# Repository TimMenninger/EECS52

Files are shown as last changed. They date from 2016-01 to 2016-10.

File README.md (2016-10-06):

# EECS52
This contains my work for EE/CS 52, in which I created and am currently writing
firmware for an MP3 player running on an Intel 80188 processor. I (TimMenninger)
am the only contributor.  When pushing/pulling from a computer in the EE lab,
I unknowingly pushed using a classmate's Git account.

Assembly (.ASM) source can be found in Software/CPU/src.  Hardware descriptions
in ABEL (.ABL) can be found in Software/ABEL/src.

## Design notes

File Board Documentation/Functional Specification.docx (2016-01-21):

# 80188 MP3 Jukebox

# Functional Specification

Tim Menninger

# Description

This is the MP3 Jukebox running on an 80188 processor. It plays MP3 files that are stored on an SD memory card or IDE hard drive. Its basic functions include:

- Skip to Next Track
- Skip to Previous Track
- Play
- Pause
- Stop
- Repeat Song
- Repeat Playlist
- Fast Forward
- Reverse
- Scan
- Volume

Each of these will be connected to a button except for volume, which will be controlled by a rotary switch. These are described in the user interface section.

Songs stored on this device will be able to range from one second to as long as memory permits. These songs will be played using an onboard MP3 decoder chip. When playing back, the MP3 Jukebox will require speakers or headphones be plugged in for music to be heard. The system will be fully functional otherwise when being used with no audio output connected.

For ease of use, the MP3 Jukebox will include an LCD status display which will display the status of the system. When the user presses a button, the screen will display a summary of what in the system has changed, if anything, and when music is playing, the screen will display the song name, artist, album if applicable and the time in the song that is being played.

# Global Variables

None.

# Inputs

## Buttons

Each function listed in Description and described in User Interface will have a button or rotary encoder. Some functions are overloaded onto the same button.

- Button 1 Play, Pause
- Button 2 Previous Track, Rewind
- Button 3 Next Track, Fast Forward
- Button 4 Stop
- Button 5 Repeat Song, Repeat Playlist, Repeat Segment
- Button 6 Scan
- Rotary Switch 1 Volume
- Rotary Switch 2 Miscellaneous

For debugging purposes, there will be a trap button, which will allow the programmer to trap the system. This button will stop the processor from reading and executing code.

- Button 7 Trap

## Power

There will be a power switch on the machine. When switched on, the machine will draw power and have the capability to play. When switched off, this capability will not exist even if a power supply is provided. There will also be an input for power supply. With no power, the MP3 Jukebox cannot play audio files.

- Switch 1 Power Switch
- Port 1 Power Supply

## Playback

In addition to these switches, there will also be an SD Card input from which songs are read and played and an audio port to plug in speakers, headphones, etc. for playback of said songs.

- SD Card Input Songs read from SD Card
- IDE Hard Drive Songs can also be read from an IDE hard drive
- Port 2 Audio Output

# Outputs

## Display

There will be an LCD display on board that displays the status of the system. This display will be four lines. Exactly what appears on this display is described in detail in User Interface.

## Audio

There will be a port that plays the music that is read from memory. Headphones, speakers, etc. can be plugged in for playback.

# User Interface

## Buttons

There is one button for both playing and pausing the song. If the state of the system is such that a file is being played, then pressing this button will pause the song. In any other state (paused, stopped) such that there is power being supplied, pressing this button will play the current song on the playlist.

There is one button for both skipping to the previous track and rewinding. When pressed, the track is not skipped until release of the button. At the release of the button, the system will skip to the beginning of the current song unless the song is in its first three seconds of playing. In this case, it will skip to the beginning of the previous song on the playlist. If the button is held for more than two seconds, then the system begins to rewind from the current place in memory until the user releases the button. The speed of rewind is 2x for the first 10 seconds of rewind (twelve seconds after initial button press) and then 4x from there after. If the beginning of the current song is reached during rewind, it will begin rewinding from the end of the previous song.

Similar to the previous/rewind button, there is one button for skipping forward and fast forwarding. Without loss of generality, this works exactly the same as rewinding except in the opposite direction. The only exception is the forward skip function always skips to the beginning of the next song on the playlist regardless of location of playback in the current song.

The stop button, when pressed, will stop play and lose the spot of the current playback. To begin playing again, the play button must be pressed and play will begin at the beginning of the playlist.

There will be a toggle option for repeating music. There can be repeat off, repeat song and repeat playlist. On repeat off, the music will stop playing at the end of the playlist. This would be equivalent to pressing stop at the end of the last song. On repeat song, the song currently playing will be repeated. This would be equivalent to pressing the previous skip every time the current song ends. Finally, there will be a repeat playlist which will begin playing from the beginning of the playlist after the end of the last song in the playlist. Finally, there will be repeat segment. When repeat segment is turned on, the location of music is remembered as point A. The user can then use the miscellaneous rotary dial to choose an offset (in time) to point B. Pressing the repeat button again will cause the system to repeat the segment from point A to point B, skipping to point A whenever point B is reached. If the time offset is 0 on the second press of the repeat button (i.e. the rotary switch was not touched), the repeat option will continue to toggle repeat options. Turning off this feature after choosing points A and B can be done by pressing the repeat button again or the scan button. The default value for this is repeat off.

The scan button will be a toggle button. When on, it will play the first [integer] seconds of each song. The integer used here can be altered by the miscellaneous rotary dial and can range from 1 to 15 seconds. At the end of those seconds, it will skip to the next song. To stop scanning, the user presses the scan button again to toggle off. This feature will respect the repeat option—if there is no repeat and scan reaches the end of the playlist, music will stop. If there is repeat song, this will continuously play the first five seconds of the same song. The default value for this is scan off and scan time 5 seconds.

The trap button will allow the user/programmer to trap into the kernel and should be used for debugging purposes only. Pressing the trap button during operation will cause the music player to stop playing.

## Dials

The volume rotary dial will control the volume of the output. This particular dial will be one that can rotate forever without reaching some bound. Rotating it counterclockwise will turn the volume down and rotating it clockwise will turn the volume up.

The miscellaneous rotary dial will be used for certain options. It will allow the user to scroll display options while the song is playing. If the user desires to repeat a segment, this dial will control the length of time that is recorded. Finally, when in scan mode, this dial will control how much time each song plays before scanning to the next song.

## Display

When a song is playing, the display will show the song title on the first line, the artist on the second line, the album on the third line and the time in the song on the fourth line. Additionally, on the fourth line on the left side will be an icon for the state of the music player. This could be the right-facing triangle for play, the double-bar pause button or double-triangles for skipping, fast forwarding and rewinding.

If the user scrolls, the bottom line of the display will change. Other display options include the repeat status (off, song, playlist, segment) of the song and a line that shows the progress into the song. When the music is stopped, nothing will be written on the display.

## Memory

Songs will be read from an IDE hard drive by default. If there is an SD chip in the SD slot, then music will be read from there.

# Error Handling

None.

# Algorithms

None.

# Data Structures

None.

# Limitations

This MP3 player currently does not play music.

# Known Bugs

None.

# Special Notes

None.

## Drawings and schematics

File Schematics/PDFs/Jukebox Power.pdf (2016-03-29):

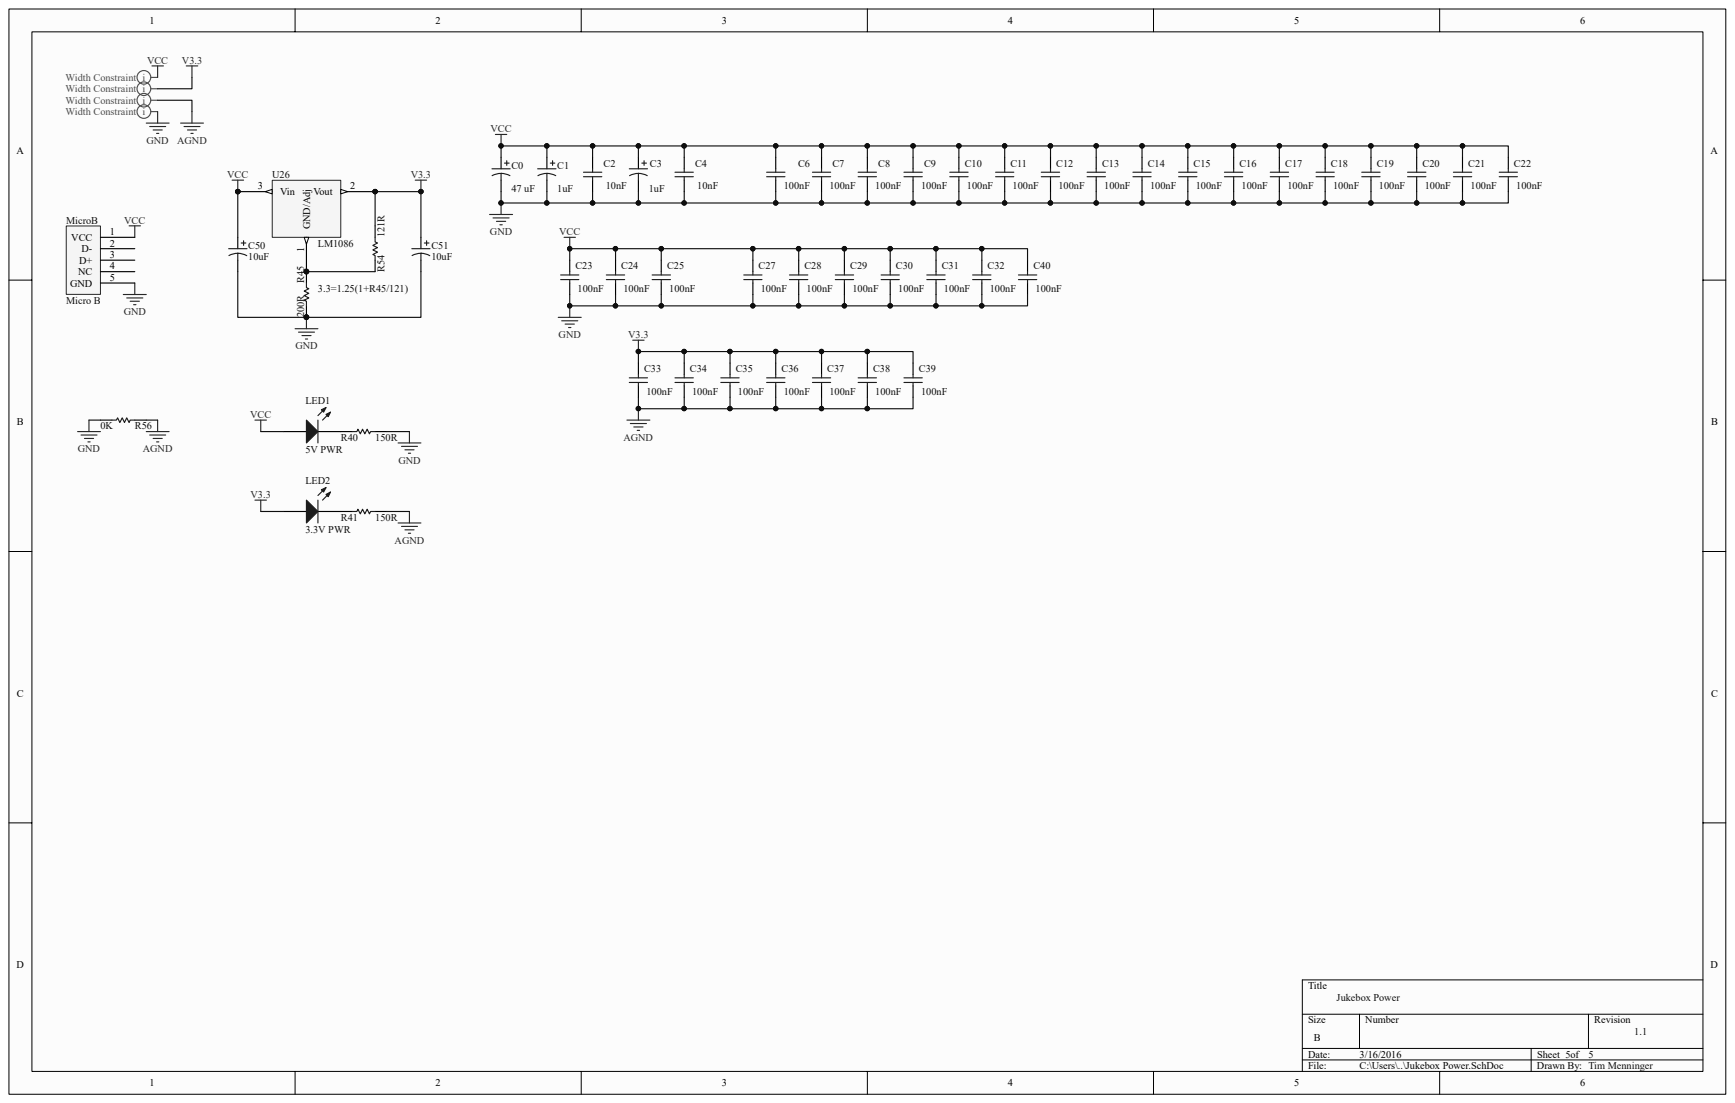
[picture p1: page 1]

Size B | Number | Revision 1.1

Date: 3/16/2016 | Sheet of 5 5
File: C:\Users\..\Jukebox Power.SchDoc | Drawn By: Tim Menninger

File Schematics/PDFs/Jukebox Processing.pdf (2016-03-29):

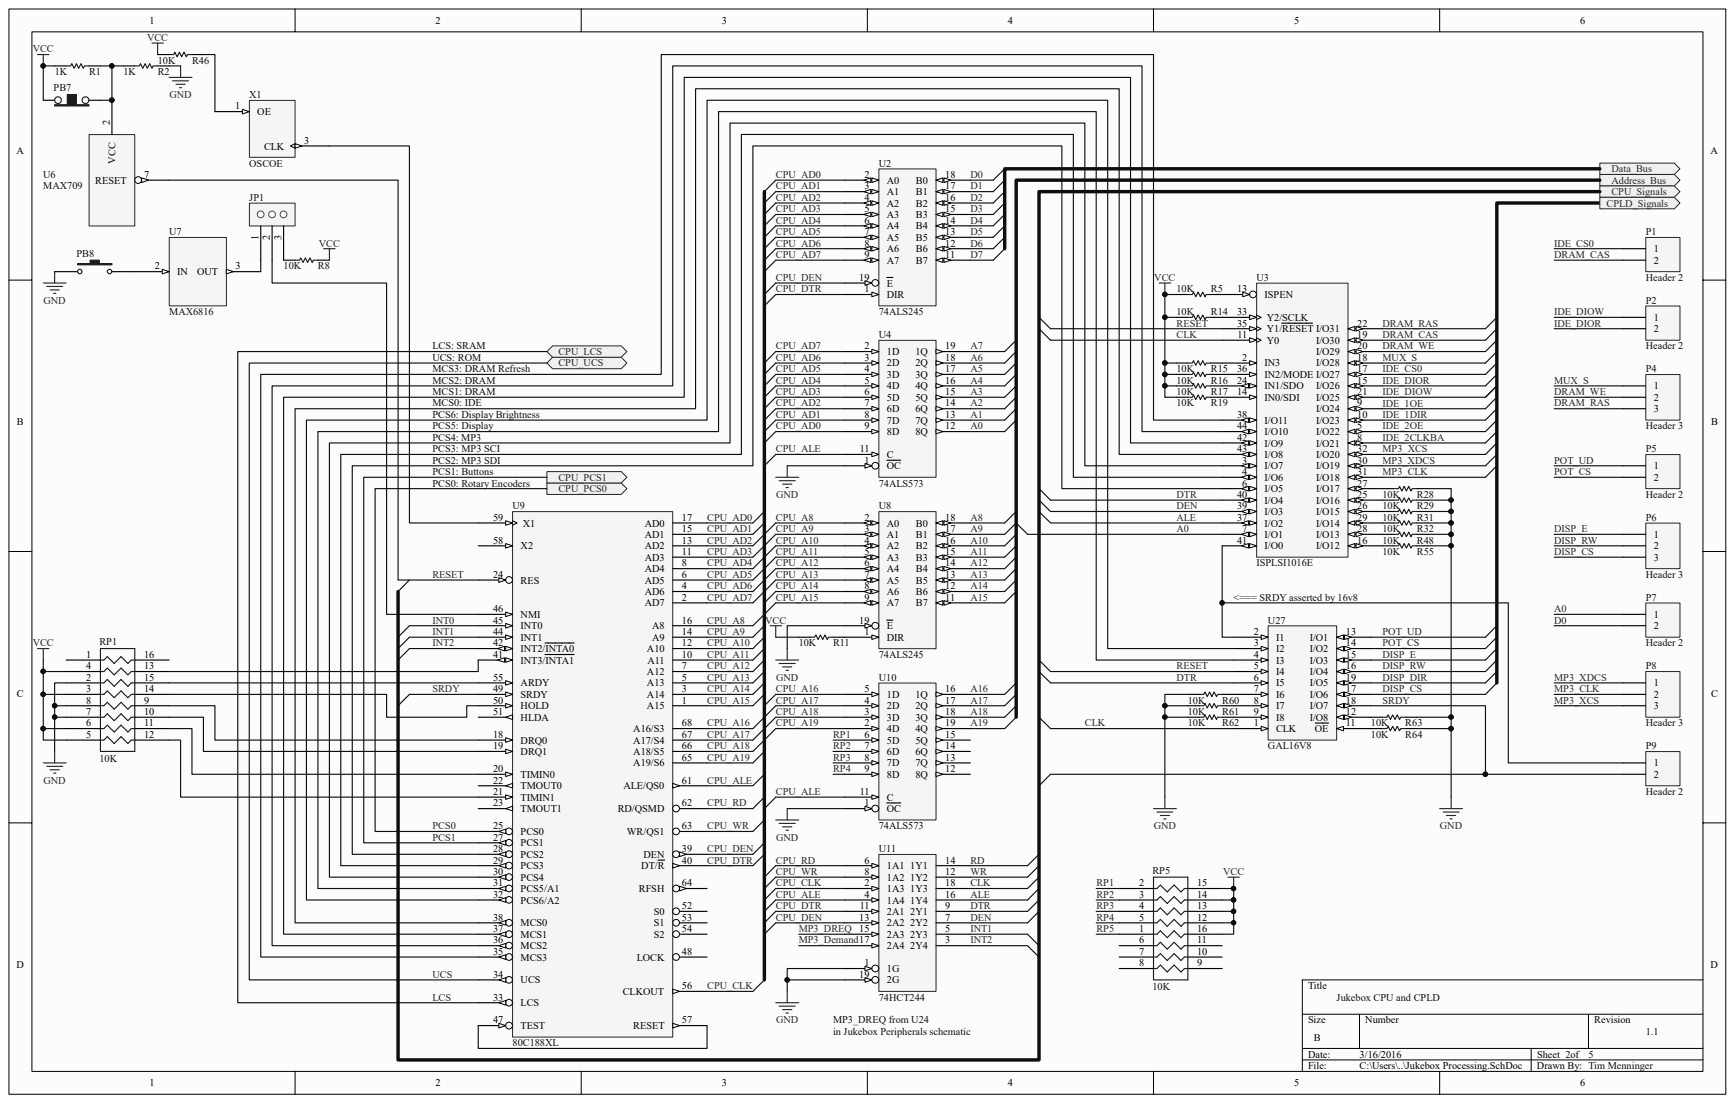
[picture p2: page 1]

CPU_AD2 | CPU_A10 | A2 4
CPU_AD3 | CPU_A11 | A3 5

CPU_AD6 | CPU_A14 | A6 8
CPU_AD7 | CPU_A15 | A7 9

Title
Jukebox CPU and CPLD

MP3_DREQ from U24
in Jukebox Peripherals schematic

Size B | Number | Revision 1.1

Date: 3/16/2016 | Sheet of 2 5
File: C:\Users\..\Jukebox Processing.SchDoc | Drawn By: Tim Menninger

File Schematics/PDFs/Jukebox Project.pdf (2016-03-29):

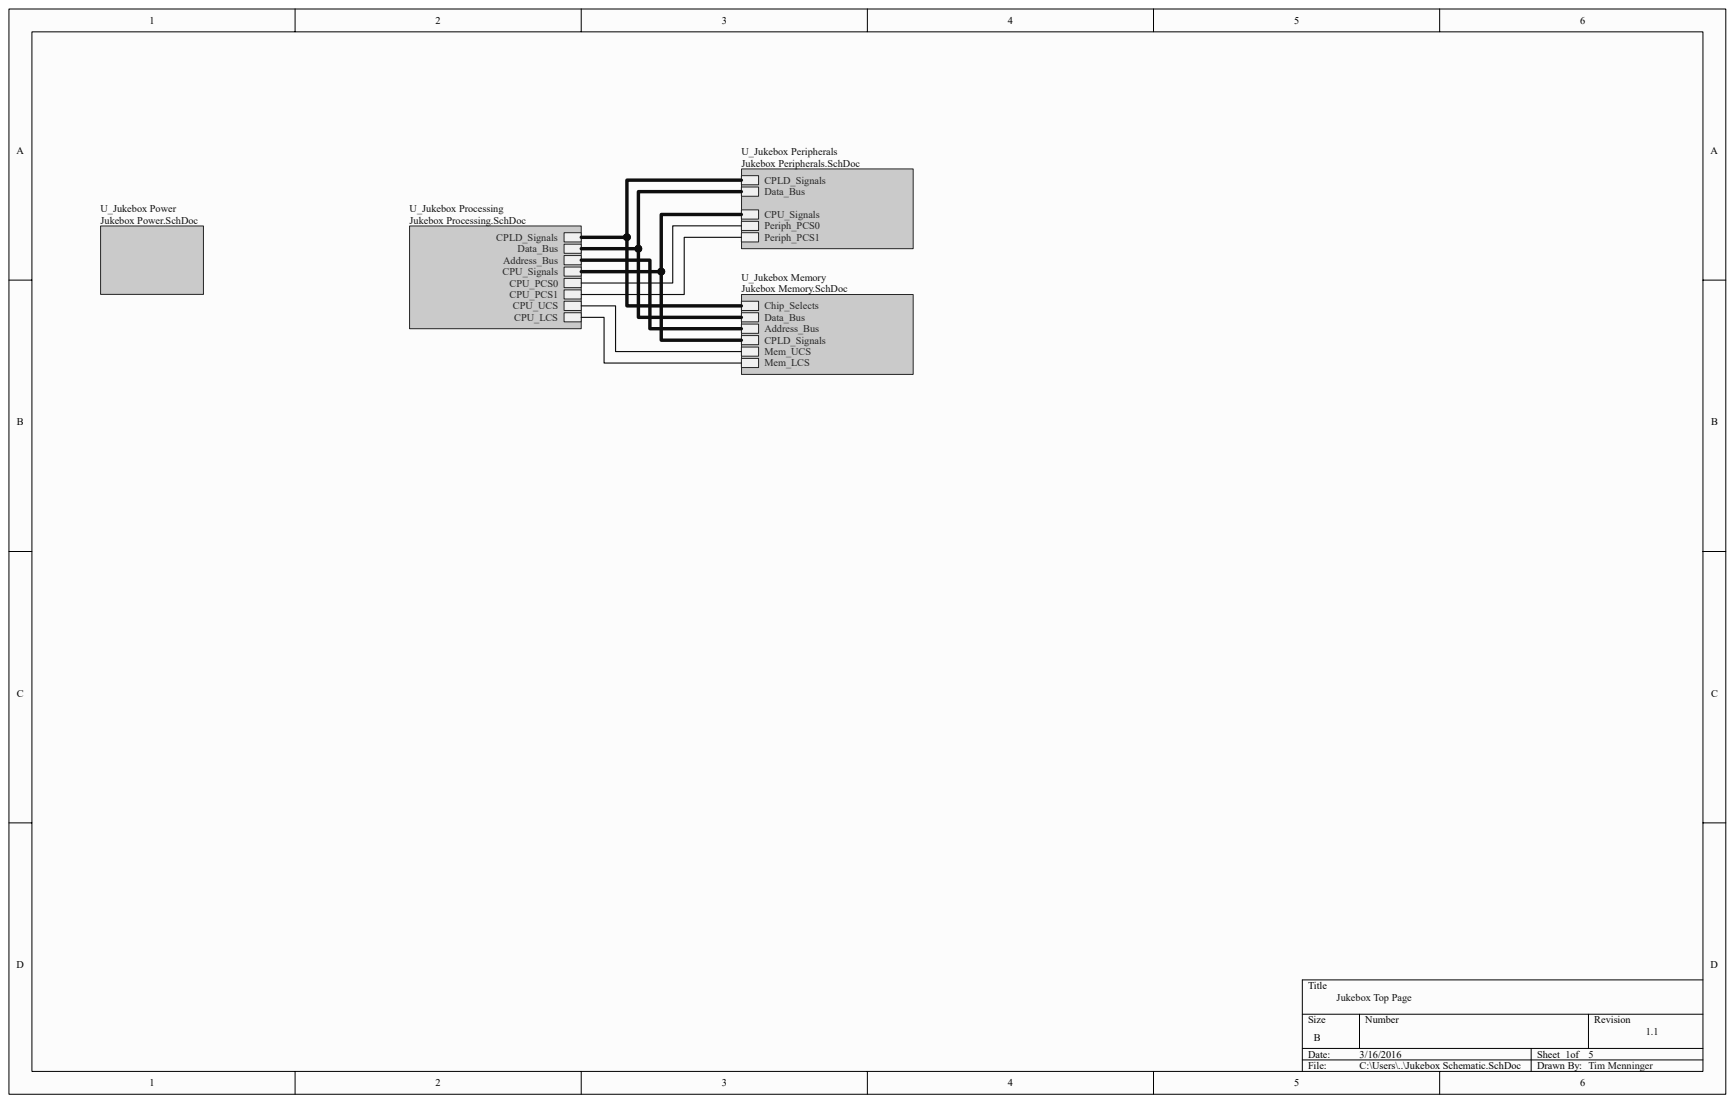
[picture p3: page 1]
CPLD_Signals Data_Bus Address_Bus CPU_Signals CPU_PCS0 CPU_PCS1 CPU_UCS CPU_LCS; CPLD_Signals Data_Bus; CPU_Signals Periph_PCS0 Periph_PCS1; U_Jukebox Peripherals Jukebox Peripherals.SchDoc; Chip_Selects Data_Bus Address_Bus CPLD_Signals Mem_UCS Mem_LCS; U_Jukebox Memory Jukebox Memory.SchDoc

U_Jukebox Power
Jukebox Power.SchDoc

U_Jukebox Processing
Jukebox Processing.SchDoc

Title
Jukebox Top Page

Size B | Number | Revision 1.1

Date: 3/16/2016 | Sheet of 1 5
File: C:\Users\..\Jukebox Schematic.SchDoc | Drawn By: Tim Menninger


CPU_AD2 | CPU_A10 | A2 4
CPU_AD3 | CPU_A11 | A3 5

CPU_AD6 | CPU_A14 | A6 8
CPU_AD7 | CPU_A15 | A7 9

Title
Jukebox CPU and CPLD

MP3_DREQ from U24
in Jukebox Peripherals schematic

Size B | Number | Revision 1.1

Date: 3/16/2016 | Sheet of 2 5
File: C:\Users\..\Jukebox Processing.SchDoc | Drawn By: Tim Menninger

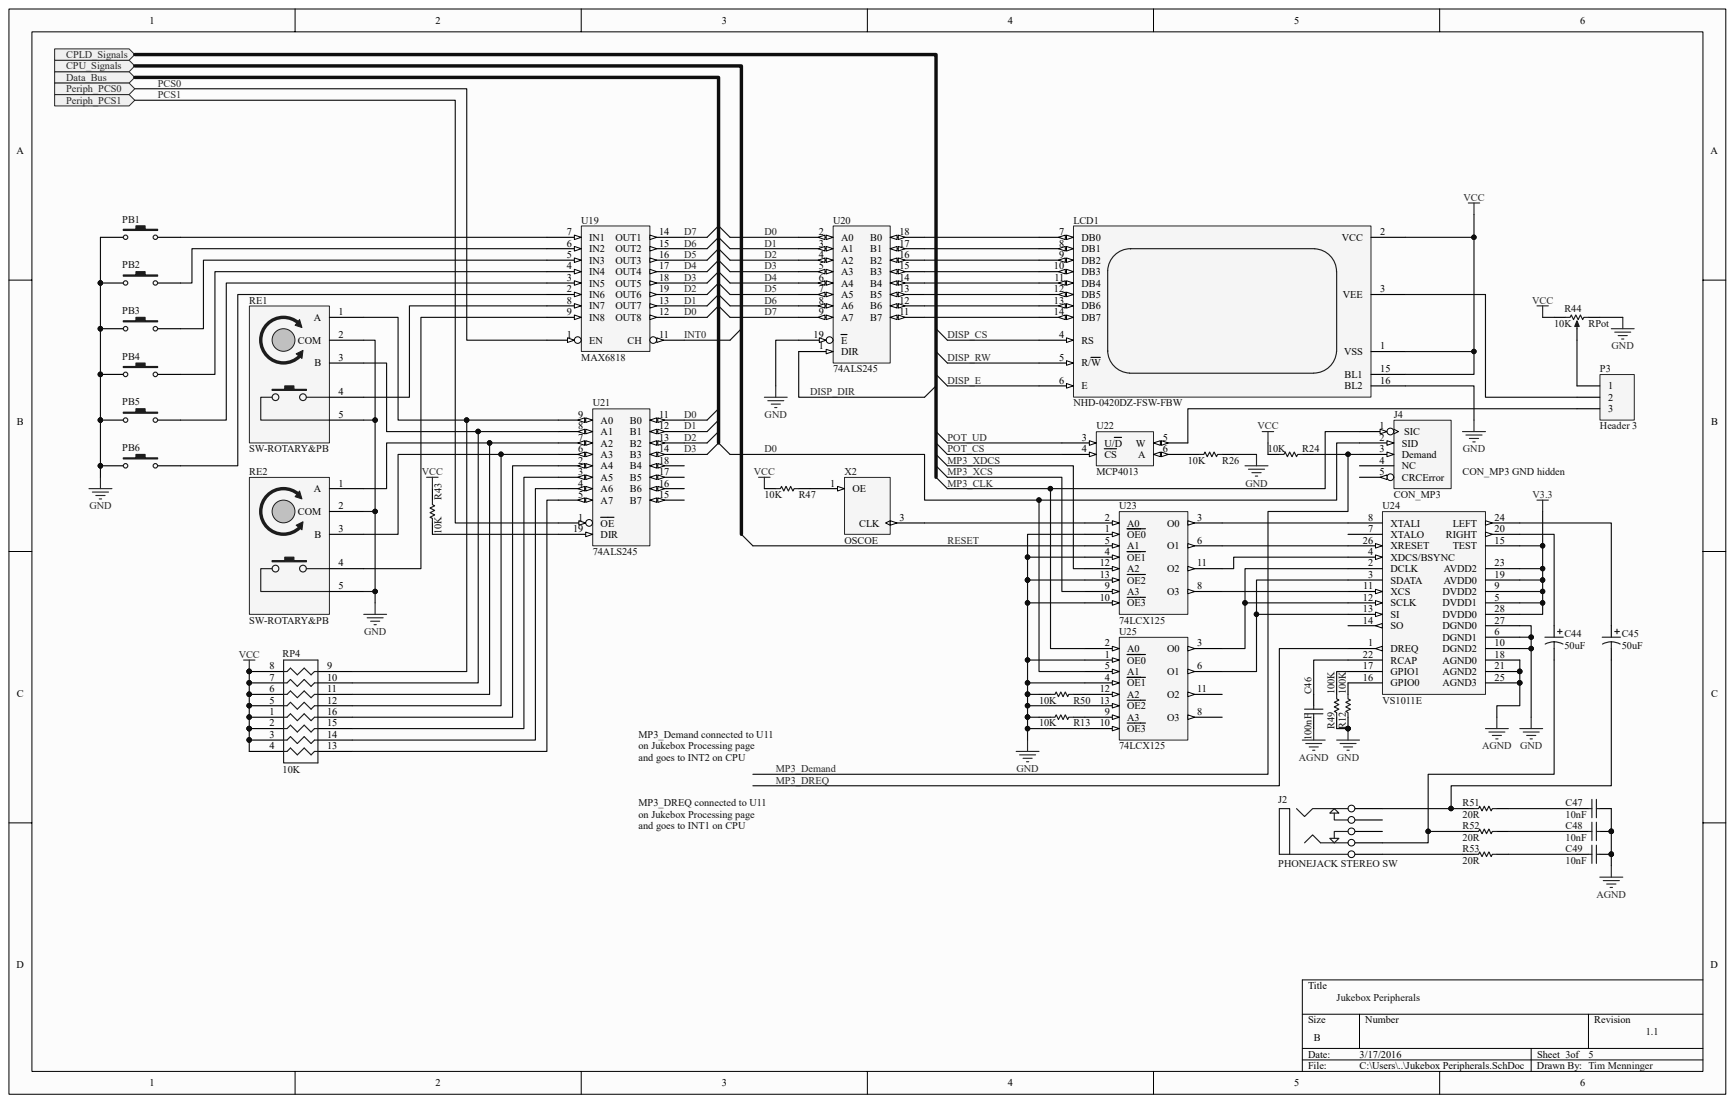
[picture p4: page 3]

MP3_Demand connected to U11
on Jukebox Processing page
and goes to INT2 on CPU

MP3_DREQ connected to U11
and goes to INT1 on CPU

Size B | Number | Revision 1.1

Date: 3/17/2016 | Sheet of 3 5
File: C:\Users\..\Jukebox Peripherals.SchDoc | Drawn By: Tim Menninger

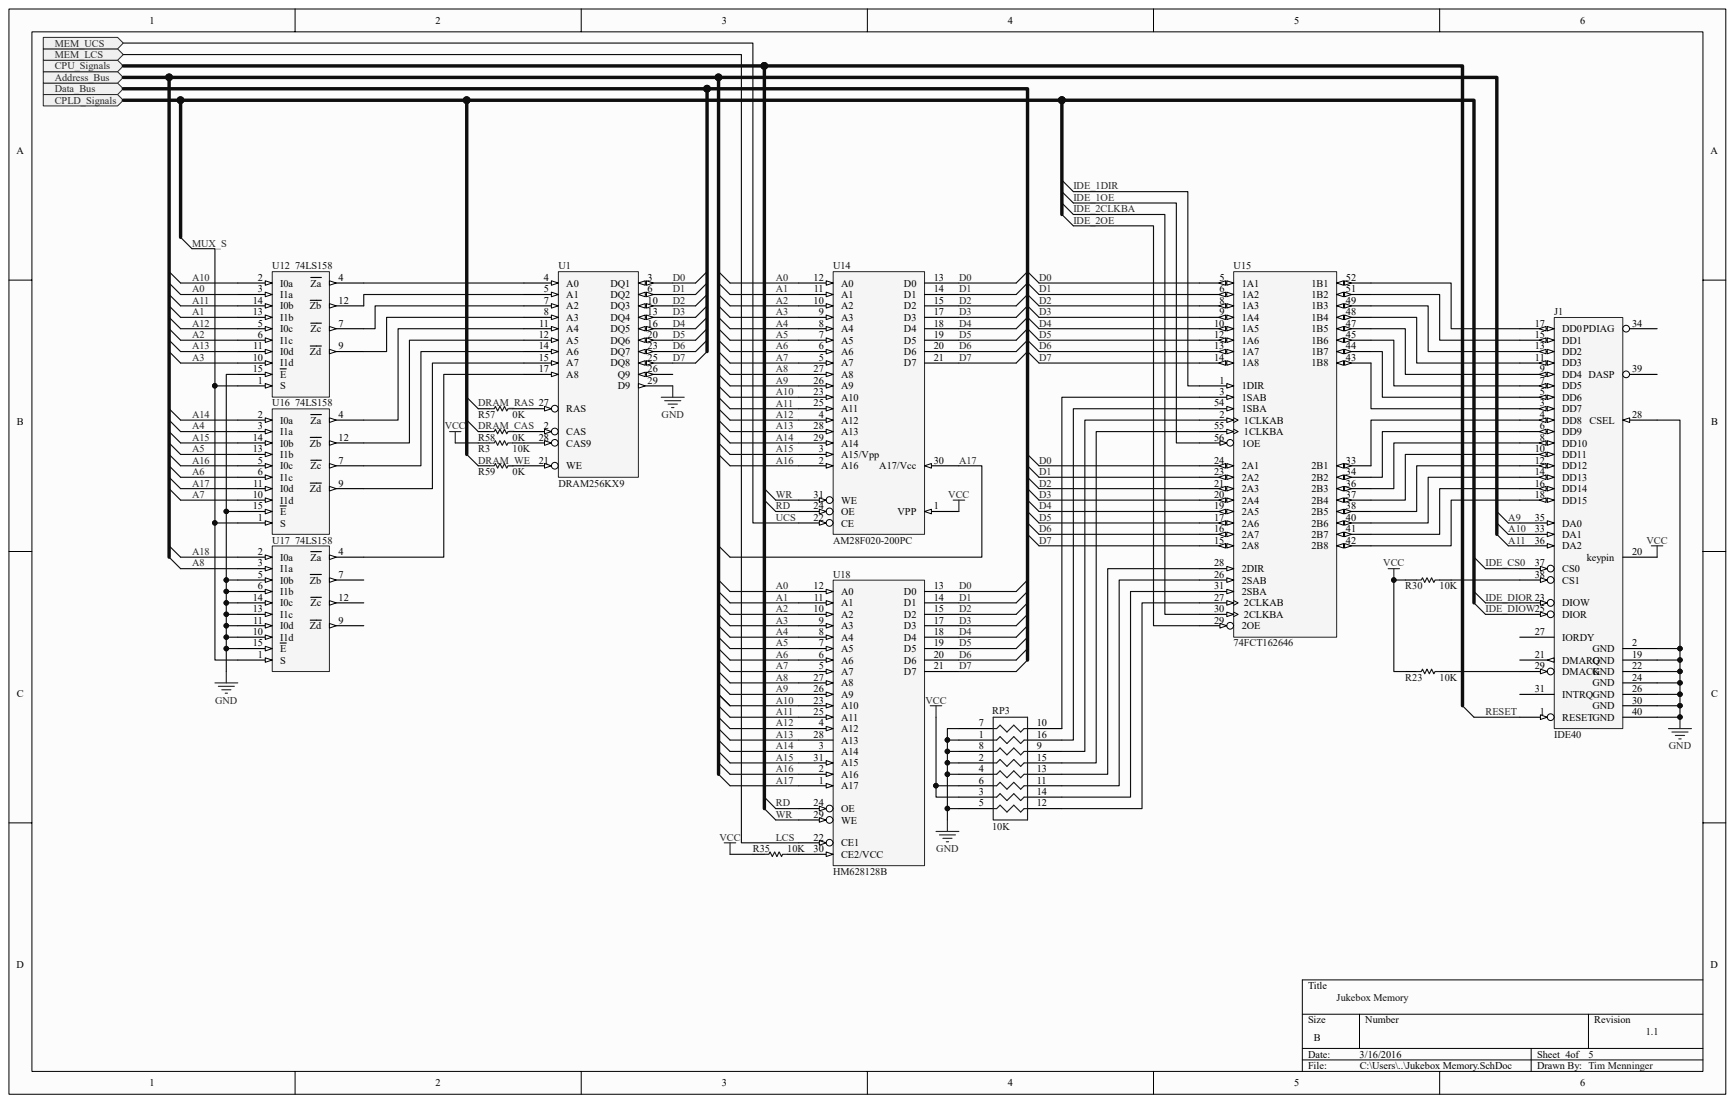
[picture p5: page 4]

Size B | Number | Revision 1.1

Date: 3/16/2016 | Sheet of 4 5
File: C:\Users\..\Jukebox Memory.SchDoc | Drawn By: Tim Menninger


Size B | Number | Revision 1.1

Date: 3/16/2016 | Sheet of 5 5
File: C:\Users\..\Jukebox Power.SchDoc | Drawn By: Tim Menninger

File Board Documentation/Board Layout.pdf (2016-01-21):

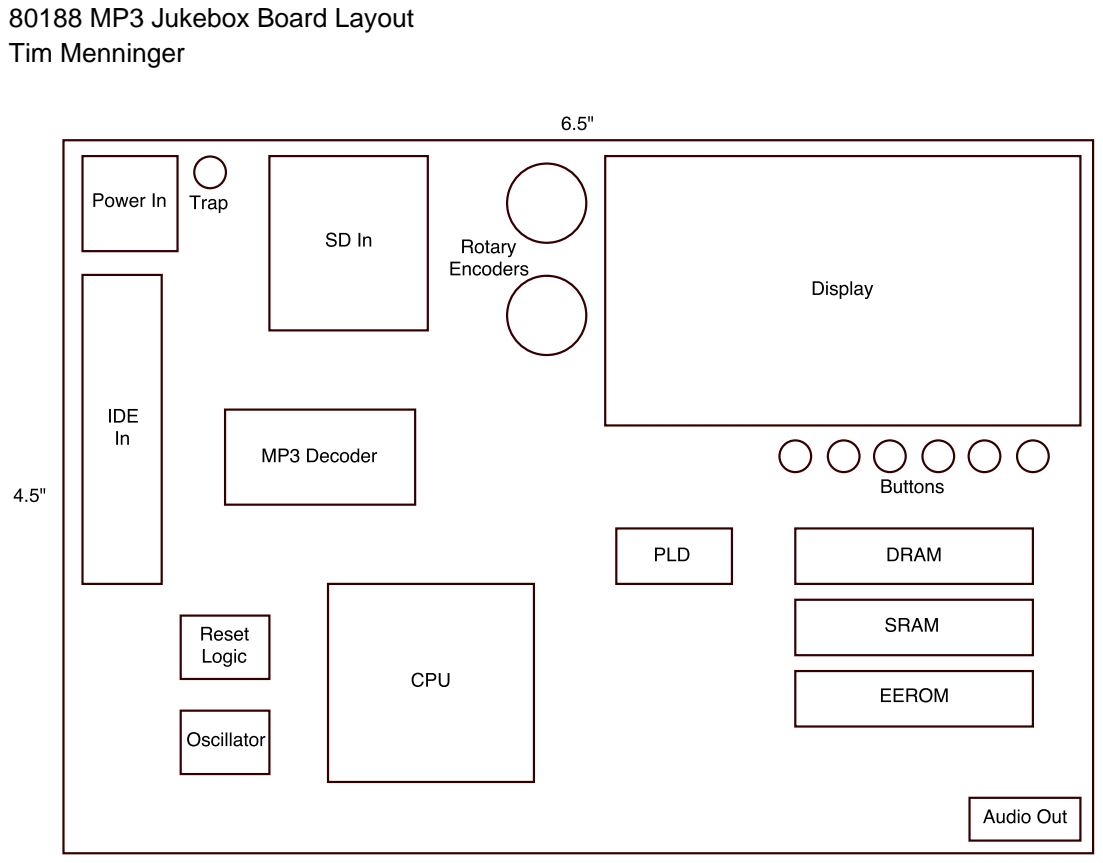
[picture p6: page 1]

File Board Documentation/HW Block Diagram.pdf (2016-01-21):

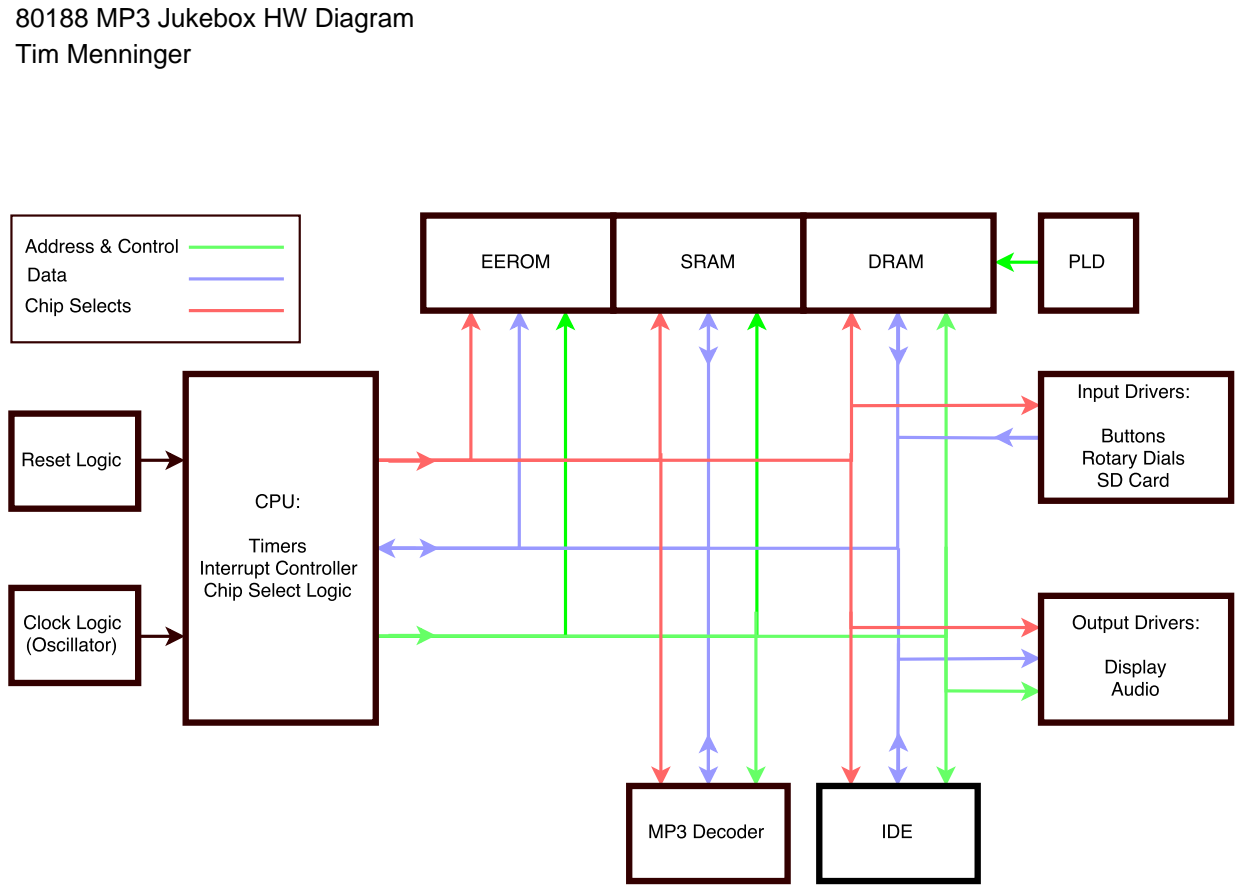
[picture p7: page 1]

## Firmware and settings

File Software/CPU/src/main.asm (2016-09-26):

    NAME MP3MAIN

;;;;;;;;;;;;;;;;;;;;;;;;;;;;;;;;;;;;;;;;;;;;;;;;;;;;;;;;;;;;;;;;;;;;;;;;;;;;;;;;;;;;;;;;;;
;                                                                                        ;
;                                         MP3MAIN                                        ;
;                              Main Loop for 80188 MP3 Jukebox                           ;
;                                      Tim Menninger                                     ;
;                                                                                        ;
;;;;;;;;;;;;;;;;;;;;;;;;;;;;;;;;;;;;;;;;;;;;;;;;;;;;;;;;;;;;;;;;;;;;;;;;;;;;;;;;;;;;;;;;;;

; Description:      This program is the main loop for the 80188 MP3 player.
;
; Input:            None.
;
; Output:           None.
;
; User Interface:   None.
;
; Error Handling:   None.
;
; Algorithms:       None.
;
; Data Structures:  None.
;
; Known Bugs:       None.
;
; Limitations:      None.
;
; Revision History: 04/21/16 - Tim Menninger: Created using wolverine.caltech.edu/eecs52
;											  resources as reference.
;




; setup code and data groups
CGROUP  GROUP   CODE
DGROUP  GROUP   DATA, STACK


; segment register assumptions
        ASSUME  CS:CGROUP, DS:DGROUP, ES:NOTHING, SS:DGROUP



; the data segment - used for static and global variables

DATA    SEGMENT  WORD  PUBLIC  'DATA'

DATA    ENDS




; the stack segment - used for subroutine linkage, argument passing, and
; local variables
STACK   SEGMENT  WORD  STACK  'STACK'

        DB      80 DUP ('Stack   ')             ;320 words

TopOfStack      LABEL   WORD

STACK   ENDS



; the actual startup code - should be executed (jumped to) after reset

CODE    SEGMENT  WORD  PUBLIC  'CODE'


        EXTRN   InitCS:NEAR             ;Initializes chip selects
        EXTRN   InitIRQ:NEAR            ;Initializes IRQ vectors
		EXTRN	InitIVT:NEAR			;Initializes interrupt vector table
		EXTRN	InitButtons:NEAR		;Initializes buttonpress queue
		EXTRN	InitEncoder:NEAR		;Initializes encoder state variable
        EXTRN   InitDisplay:NEAR        ;Clears display
        EXTRN   InitTimer:NEAR          ;Initializes timer
        EXTRN	main:NEAR				;Main loop provided by Glen


Start:

        CLI
        
        MOV     AX, DGROUP              ;initialize the stack pointer
        MOV     SS, AX
        MOV     SP, OFFSET(TopOfStack)

        MOV     AX, DGROUP              ;initialize the data segment
        MOV     DS, AX

        CALL    InitCS                  ;initialize chip selects
        CALL    InitIRQ                 ;initialize and clear IRQ vectors
		CALL	InitIVT					;Initializes interrupt vector table
        CALL    InitTimer               ;Initializes timer 0
		CALL	InitButtons				;Initializes buttonpress queue
		CALL	InitEncoder				;Initializes encoder state variable
        CALL    InitDisplay             ;Clears display and local cache
        
        STI

        CALL    main					;call main loop provided by Glen

        JMP     Start                   ;main does not return, here by error



CODE    ENDS



        END Start

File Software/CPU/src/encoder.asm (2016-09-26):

		NAME	ROTARY_ENCODERS

;;;;;;;;;;;;;;;;;;;;;;;;;;;;;;;;;;;;;;;;;;;;;;;;;;;;;;;;;;;;;;;;;;;;;;;;;;;;;;;;;;;;;;;;;;
;                                                                                        ;
;                                       ENCODER.ASM                                      ;
;                             Code for rotary encoder routines                           ;
;                                      Tim Menninger                                     ;
;                                                                                        ;
;;;;;;;;;;;;;;;;;;;;;;;;;;;;;;;;;;;;;;;;;;;;;;;;;;;;;;;;;;;;;;;;;;;;;;;;;;;;;;;;;;;;;;;;;;

;
;Description:      This has the code that handles rotation of the rotary encoder on the
;				   80188 MP3 player.
;
;Contents:         InitEncoder - initializes the encoder state variable to the initial
;						encoder state
;                  EncoderHandler - responds to interrupts causted by rotation in the
;						encoder
;
;Input:            Rotary Encoder - This reads from the encoder in initialization, then
;						again each time a rotation drives an interrupt.  It uses these
;						values to determine which direction it was turned.
;
;Output:           None.
;
;Error Handling:   None.
;
;Data Structures:  None.
;
;Revision History: 09/19/16    Tim Menninger   Created
;

CGROUP  GROUP   CODE
DGROUP  GROUP   DATA

CODE    SEGMENT PUBLIC 'CODE'

        ASSUME  CS:CGROUP, DS:DGROUP


$INCLUDE(src\encoder.inc)           ;Constants related to buttons
$INCLUDE(src\intrpts.inc)           ;Constants used for encoder interrupts

;
;InitEncoder
;
;Description:       Initializes the state variable that is used to compare to the encoder
;					and decide what direction it is turning.
;
;Operation:         This reads the data from the rotary encoder's debouncer and stores it
;					in a shared state variable.
;
;Arguments:         None.
;
;Return Value:      None.
;
;Local Variables:   None.
;
;Shared Variables:  EncoderState (WRITE) - Sets the EncoderState variable to the initial
;						state of the rotary encoder.
;
;Global Variables:  None.
;
;Input:             Rotary Encoder - This reads from the button debouncer connected to
;						the rotary encoder
;
;Output:            None.
;
;Error Handling:    None.
;
;Algorithms:        None.
;
;Data Structures:   None.
;
;Registers Changed: AX, DX
;
;Revision History:  09/19/16   Tim Menninger   Created
;
InitEncoder     PROC        NEAR
                PUBLIC      InitEncoder

ReadInitialState:
	MOV		DX, ENCODER_PORT	;want initial encoder state for future turns
	XOR		AX, AX				;clear high byte because reading only byte
	IN		AL, DX				;read encoder state
	MOV		EncoderState, AL	;store encoder state
    RET

InitEncoder		ENDP


;
;EncoderHandler
;
;Description:       This is called in response to interrupts driven by rotation in the
;					rotary encoder.  It uses the previously known state and the new state
;					to decide which way the encoder rotated, then updates the system
;					accordingly.
;
;Operation:         Reads from the debouncer relaying encoder state.  Then stores the
;					previous state and updates the shared variable with the new state.
;					It puts the previous state in the 2nd and 3rd bits of a register and
;					the current state in the 0th and 1st bits of the same register, then
;					uses that number to index a table.  The table is set up such that
;					each index corresponds to exactly one direction (counterclockwise,
;					clockwise, no motion, unable to be determined).  The table contains
;					the offset of the function to run on the given previous/current state
;					combination.
;
;Arguments:         None.
;
;Return Value:      None.
;
;Local Variables:   DI - contains current encoder state, then both states in different
;						bits
;					AX - contains previous encoder state
;
;Shared Variables:  EncoderState (WRITE) - The value in this is read as the previous
;						value, then the value read from the encoder is stored in its
;						place in EncoderState
;
;Global Variables:  None.
;
;Input:             Rotary Encoders - The state is read and the function changes the
;						system setting accordingly.
;
;Output:            None.
;
;Error Handling:    If the previous and current states correspond to either (1) there
;					was no rotation or (2) there were two rotations, then which direction
;					the encoder was turned cannot be determined.  In this case, no action
;					is taken.
;
;Algorithms:        None.
;
;Data Structures:   None.
;
;Registers Changed: None.
;
;Revision History:  09/19/16   Tim Menninger   Created
;
EncoderHandler	PROC		NEAR
				PUBLIC		EncoderHandler

	PUSHA						;store registers

ReadEncoderState:
	XOR		AX, AX				;clear high byte because only reading byte
	IN		AL, ENCODER_PORT	;read encoder state
	MOV		DI, AX				;make copy to retain next value
	XCHG	EncoderState, AL	;get encoder state to check which direction it moved

DecideEncoderMotion:
	AND		AX, STATE_MASK		;mask out bits that don't relate to last encoder state
	AND		DI, STATE_MASK		;mask out bits that don't relate to current encoder state
	SHL		AX, STATE_BITS		;shift last state so we can combine the two states
	OR		DI, AX				;combine two states to use as table lookup
    XOR     AX, AX              ;sending 0 to potentiometer

	JMP		CS:EncoderFunctions[DI];handle function accordingly

HandleClockwise:
    MOV		DX, POT_PORT_UP		;port for digital potentiometer to change brightness
	OUT		DX, AL				;turn up display brightness
	JMP		EncoderHandled

HandleCounterclockwise:
    MOV		DX, POT_PORT_DOWN   ;port for digital potentiometer to change brightness
	OUT		DX, AL				;turn down display brightness
	JMP		EncoderHandled

EncoderHandled:
	MOV     DX, INTCtrlrEOI     ;EOI control register address
	MOV     AX, EncoderEOI      ;End of interrupt value
	OUT     DX, AX			    ;write end of interrupt
	POPA
	IRET

EncoderHandler	ENDP


;
;EncoderFunctions
;
;Description:	This is a table of functions that are called in response to the rotary
;				encoder's direction of rotation.  It is indexed by four-bit integers
;				where b3 and b2 represent the previous state and b1 and b0 represent the
;				next state.
;
;Author:       	Tim Menninger
;Last Changed: 	09/19/16
;
EncoderFunctions LABEL   WORD
				 PUBLIC  EncoderFunctions
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

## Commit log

2016-01-21 Added docs from HW 1
    [CPU Circuitry.xlsx, Memory Map.xlsx]
2016-01-22 Put RAM and ROM in schematic.
    [Jukebox Schematic.SchDoc]
2016-01-22 Added some connections (HW2)
    [Jukebox Schematic.SchDoc]
2016-01-22 Finished ROM and RAM on schematic.
    [Jukebox Schematic.SchDoc]
2016-01-23 Added 0.1uF caps
    [Jukebox Schematic.SchDoc]
2016-01-23 Changed names of parts to be neater
    [Jukebox Schematic.SchDoc]
2016-01-23 Small changes
    [Jukebox Schematic.SchDoc]
2016-01-23 Cleaned up
    [Jukebox Schematic.SchDoc]
2016-01-25 Fixed Peter's changes and added datasheets
    [Jukebox Schematic.SchDoc]
2016-01-25 Cleaned up schematic
    [Jukebox Schematic.SchDoc]
2016-01-25 Once more for good measure
    [Jukebox Schematic.SchDoc]
2016-02-01 PCB added and some datasheets.
    [Jukebox PCB.PCBDOC, Jukebox Project.PrjPCB, Jukebox Schematic.SchDoc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]
2016-02-01 Schematic part for rotary encoder
    [AS5115.SchLib]
2016-02-02 Added buttons and rotary encoders
    [Jukebox PCB.PCBDOC, Jukebox Project.PrjPCB, Jukebox Schematic.SchDoc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]
2016-02-06 Timing diagrams for SRAM ROM
    [Jukebox PCB.PCBDOC]
2016-02-06 Forgot to save
    [Jukebox Schematic.SchDoc]
2016-02-09 Display and buttons outline
2016-02-09 Timing diagrams
    [Jukebox PCB.PCBDOC, Jukebox Schematic.SchDoc]
2016-02-09 Timing equations
    [timing.xlsx]
2016-02-09 Timing xlsx
    [timing.xlsx]
2016-02-12 IDE and MP3 decoder to schematic
    [Jukebox PCB.PCBDOC, Jukebox Project.PrjPCB, Jukebox Schematic.SchDoc]
2016-02-23 Datasheets, MP3, IDE
    [Jukebox PCB.PCBDOC, Jukebox Project.PrjPCB, Jukebox Schematic.SchDoc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]
2016-03-29 Datasheets added
    [Jukebox PCB.PCBDOC, Jukebox Project.PrjPCB, Jukebox Schematic.SchDoc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]
2016-03-29 Trying to add datasheets
    [Jukebox - Copy.PCBDOC, Jukebox Memory.SchDoc, Jukebox Peripherals.SchDoc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]
2016-09-19 buttons and encoder code
    [Memory Map.xlsx]
2016-09-25 syntax errors in gal16v8.abl
    [Jukebox Memory.SchDoc, Jukebox Peripherals.SchDoc, Jukebox Processing.SchDoc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]
2016-09-25 gal16v8 only does display now
    [isplsi1016.sdf]
2016-09-26 added empty ints abel code to run on buttons
2016-09-26 abel files to download to chip
    [ints.sdf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]
2016-09-26 ints ABEL code
    [ints.sdf]
2016-09-26 started debugging, added timers. can't figure out why interrupt requests aren't being handled
2016-11-03 deleted garbage
    [Jukebox - Copy.PCBDOC, Jukebox Project.PrjPCB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]
